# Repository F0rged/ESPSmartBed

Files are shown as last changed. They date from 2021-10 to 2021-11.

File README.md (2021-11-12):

# ESPSmartBed V1.0
Smart Bed using ESP8266 and integrated scale via HX711
Version 1.0 Notes:
- LED resistor seems to cause issues.  Use a wire instead of a resistor.
- Some HX711 sensors seem to be defective.  Not sure how to test ahead of time...
- circuit board can be uploaded to JLCPCB and you can order 10 for like $8 plus shipping.
- circuit board positive and negative nets are undersized for lots of LEDs.  Should be increased in later revisions..
- Its important for the HX711 to be close to the ESP8266 as its a high speed connection.  The strain guage sensors can be farther away, but use shielded wire.

Parts List:
- ESP8266 (Wemos D1 Mini Clone)
- HX711 (with 4 sensors each) - can handle up to 3 (3 HX711s and 12 sensors)
- Up to 3 MCP23008 chips for additional inputs and outputs (buttons etc)
- Slots for 8 buttons on the board (tied into one of the MCP23008) - not tested yet.
- 100 uF capacitor
- barrel jack connector

Inspired by:
https://synapselabs.io/posts/bed-sensor-with-esphome-on-homeassistant/
https://www.reddit.com/r/homeassistant/comments/856yav/i_made_a_stupidly_accurate_bed_occupancy_sensor/
https://everythingsmarthome.co.uk/howto/building-a-bed-occupancy-sensor-for-home-assistant/

Custom Bed with WS2812B LEDs

Circuit Board

Case

Case Mounted

Final Result

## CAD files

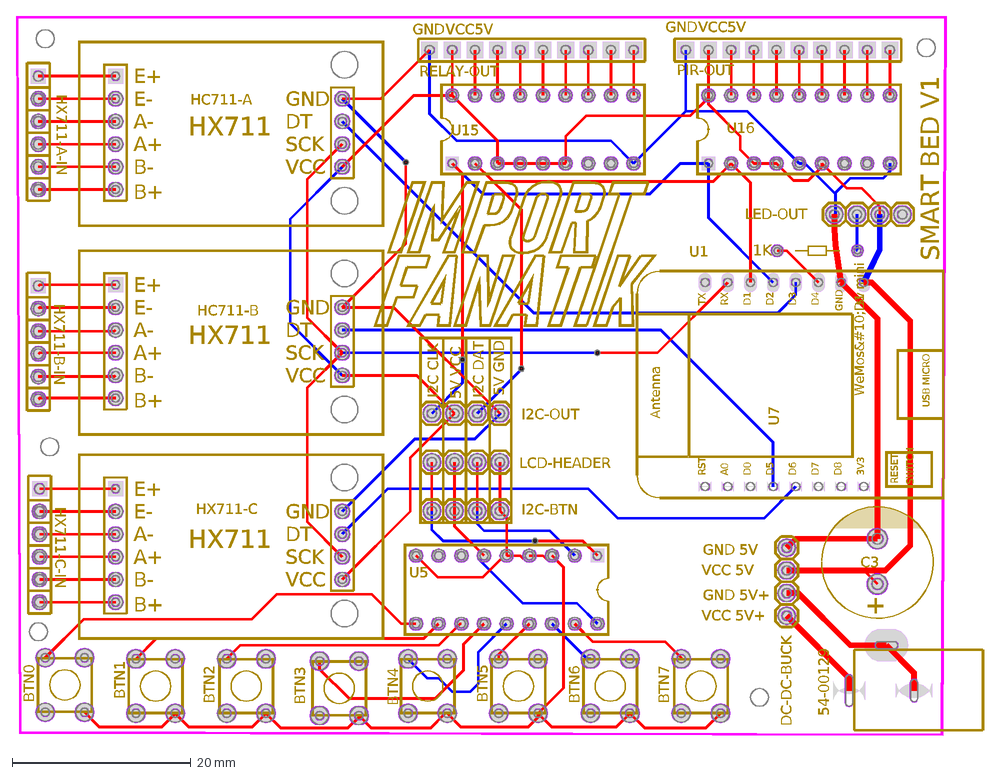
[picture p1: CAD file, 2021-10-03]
CircuitBoard/PCB_ESPSmartBed_2021-09-26.dxf
5V GND
I2C DAT
5V VCC
I2C CLK
VCC 5V
GND 5V
GND 5V+
VCC 5V+
GND
VCC5V
SMART BED V1
54-00129
BTN3
BTN4
C3
PIR-OUT
U5
U15
U16
HC711-A
HX711
E+
E-
A-
A+
B-
B+
DT
SCK
VCC
HC711-B
HX711-C
HX711-A-IN
HX711-B-IN
HX711-C-IN
I2C-OUT
LCD-HEADER
I2C-BTN
LED-OUT
DC-DC-BUCK
RELAY-OUT
U1
1K
U7
WeMos&#10;D1 mini
RST
A0
D0
D5
D6
D7
D8
3V3
5V
D4
D3
D2
D1
RX
TX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

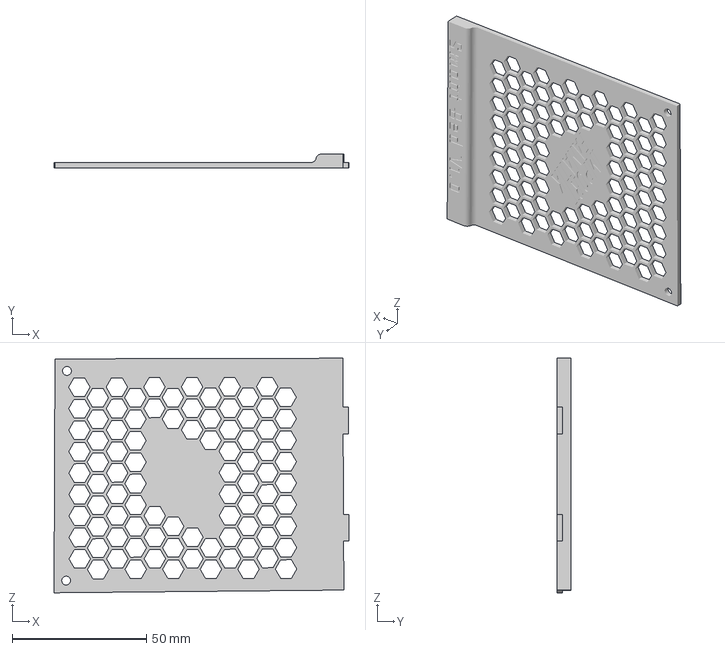
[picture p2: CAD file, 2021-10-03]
ControlUnitCase/CaseTop.3mf
109.9 x 5.20 x 87.4 mm

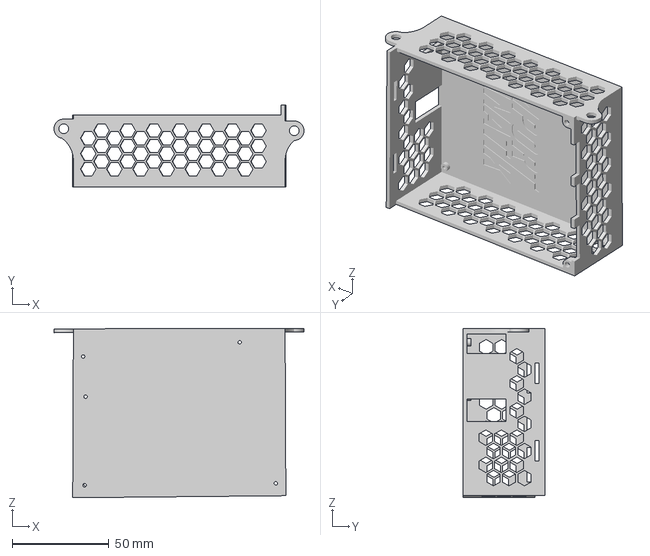
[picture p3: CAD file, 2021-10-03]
ControlUnitCase/CaseBottom.3mf
129.0 x 42.2 x 87.5 mm

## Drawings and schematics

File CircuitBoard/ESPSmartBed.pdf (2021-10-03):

### 5V+ Power

### DC-DC Buck Converter

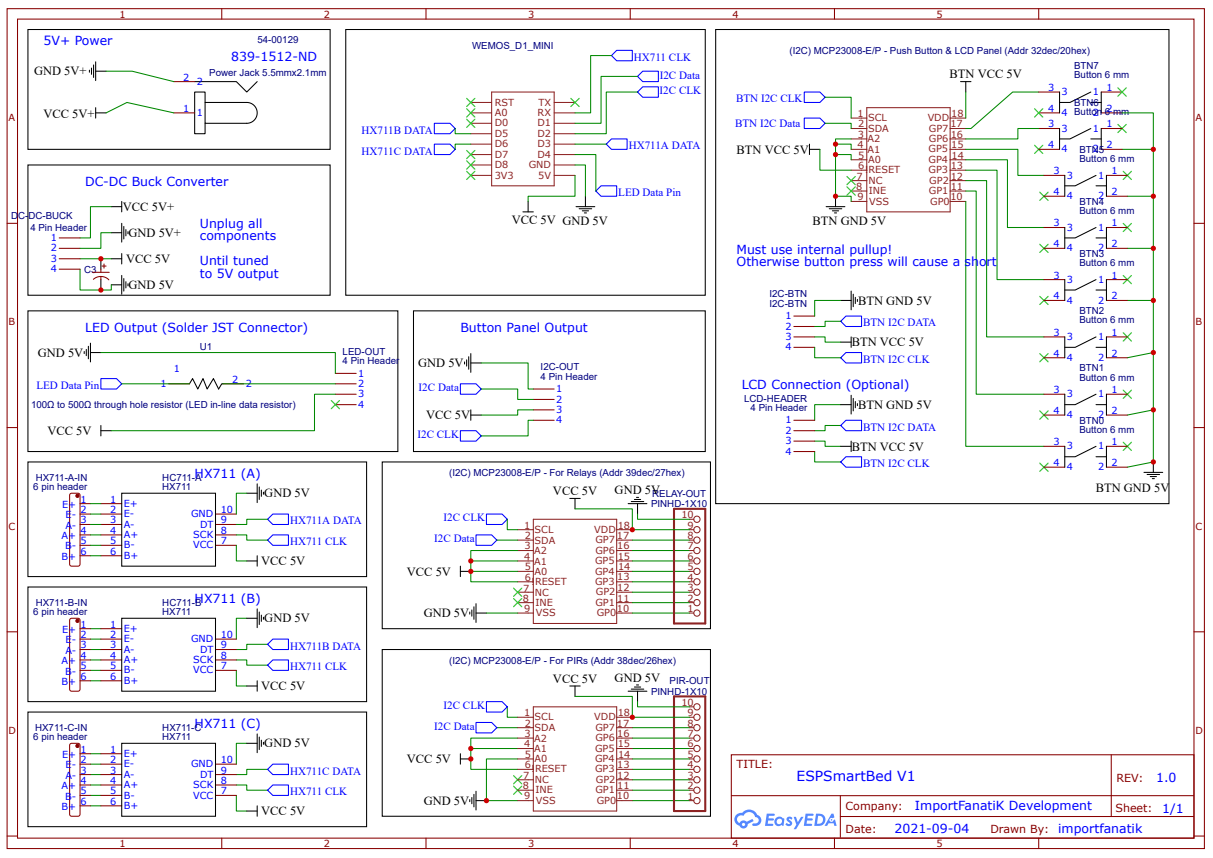
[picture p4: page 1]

(I2C) MCP23008-E/P - Push Button & LCD Panel (Addr 32dec/20hex)

Must use internal pullup!
Otherwise button press will cause a short

LED Output (Solder JST Connector)

100Ω to 500Ω through hole resistor (LED in-line data resistor)
VCC 5V

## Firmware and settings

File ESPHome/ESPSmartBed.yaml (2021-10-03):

light:
  - platform: fastled_clockless
    chipset: WS2812B
    pin: D4
    num_leds: 22
    rgb_order: GRB
    name: "Master Bed Light"
    id: masterbedlight
    effects:
      - addressable_rainbow:
          name: Rainbow Effect With Custom Values
          speed: 10
          width: 50
      - addressable_lambda:
          name: SideA
          update_interval: 50ms
          lambda: |-
            //Define Variables
            static uint16_t progress = 8;
          
            //set all to black initially
            if (initial_run) {
              progress = 8;
              it.all() = Color::BLACK;
            } else if (progress < 22){
              it[progress] = Color::WHITE;
              progress++;
            } else {
              return;
            }
      - addressable_lambda:
          name: SideB
          update_interval: 100ms
          lambda: |-
            //Define Variables
            static uint16_t progress = 0;
          
            //set all to black initially
            if (initial_run) {
              progress = 0;
              it.all() = Color::BLACK;
            } else if (progress == 7){
              it[progress] = Color::WHITE;
              progress = 21;
            } else if (progress == 16){
              it[progress] = Color::WHITE;
              progress = 99;
              return;
            } else if (progress == 99){
              return;
            } else if (progress > 16){
              it[progress] = Color::WHITE;
              progress--;
            } else if (progress < 7){
              it[progress] = Color::WHITE;
              progress++;
            }

sensor:
  - platform: hx711
    name: "HX711 A"
    dout_pin: D3
    clk_pin: RX
    gain: 128
    update_interval: 1s
    filters:
      - calibrate_linear:
          - 390761 -> 0
          - 1292942 -> 178
    unit_of_measurement: lbs
    
  - platform: hx711
    name: "HX711 B"
    dout_pin: D5
    clk_pin: RX
    gain: 128
    update_interval: 1s
    filters:
      - calibrate_linear:
          - 2797567 -> 0
          - 6094847 -> 178
    unit_of_measurement: lbs
